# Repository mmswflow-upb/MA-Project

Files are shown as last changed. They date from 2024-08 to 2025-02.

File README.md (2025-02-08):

# Microprocessor Architecture Project 🦀
For more details check the [documentation](DOCUMENTATION.md) and how to [set it up](PROJECT-SETUP.md).

## What is this project about?
We had to create a device using electronic components such as sensors, motors, etc and control them using an MCU of 
our choice. The firmware had to be written in Rust using any framework we wanted, I've decided to use the 
[RP Pico W](https://www.raspberrypi.com/documentation/microcontrollers/pico-series.html#raspberry-pi-pico-w) with 
the [embassy](https://embassy.dev/) framework because it was the same one we had been using during the labs. We also had 
to fork the repository of the [course's website](https://embedded-rust-101.wyliodrin.com/) and add our own project 
presentations, then we had to create pull requests that were tested before merging.

## How did it go?
At first I was unsure of what I wanted to create, but then I tried to go with one idea and develop it incrementally. It was 
tough to work with embassy due to my unfamiliarity with the Rust language, it's a pretty tough language to learn and we had
little time to get used to it.

One of the obstacles was trying to work with modules or libraries, which would help me with 
operating the peripherals connected to my MCU such as the LCD screen or the WIFI chip, 
this is because the community is pretty small and I had to try a couple different modules 
until I found an actual working one.

The toughest part was coming up with the logic for my project, since I had to expect input both 
from a tactile physical remote and an application on the PC simultaneously. This part took
the longest time to finish, because I had to connect my MCU to my laptop each time I tested
the feature.

## What did I learn?
I learned how to work with electronic components, MCUs, I studied communication 
protocols between integrated circuits, I learned some rust along with the embasssy framework, 
I also learned more about app development (with Python), and I learned how to use KiCad and GitHub.

Overall, it was a wonderful learning experience 💪💪

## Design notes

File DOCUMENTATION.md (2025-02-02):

# DIY Laptop Cooling Pad
A cooling Pad for laptops that can be controlled wirelessly or using buttons.

:::info

**Author**: Sakka Mohamad-Mario \
**GitHub Project Link**: https://github.com/mmswflow-upb/MA-Project

:::

## Description

There are 2 possible ways of using it:
* Physically: The fans are controlled through a tactile UI made up of a screen which displays info and buttons with which we increase or decrease the speed of the fans.

* Wirelessly: A user can interact with the microcontroller through a desktop app which sends commands to it through WIFI.

## Motivation

The average temperature around the globe has been on the rise for quite a while, and personally I'm very sensitive to heat, so the first thing that came to my mind was making a fan. After a while I realised that, because I use my laptop for long periods of time doing multiple things including gaming, I also wanted to cool down my laptop's since its keyboard gets pretty hot sometimes when playing games, so I've moved on to this idea. I also wanted the coolers to be controlled using an app on my laptop through wireless connection, without necessarily having to open it, instead I could use key bindings that are preset for the app and I could have the app running in the background.

## Architecture

* The application on the laptop will act as a server, the RP Pico W will establish a connection and it will exchange data with it via TCP to ensure reliable communication between the two. This app will be written in *Python* using the *TTKBootstrap & Socket* modules and it will be converted into an executable. The RP PICO W will connect to a network with preset name & password which must be hosted by the laptop. The
program running on the RP Pico W will be written using the *embassy-rs* framework.

* The physical UI (buttons & LCD) will be used to establish the connection, increase or decrease fan speed, power on or off the setup, with all necessary info being displayed on the LCD.

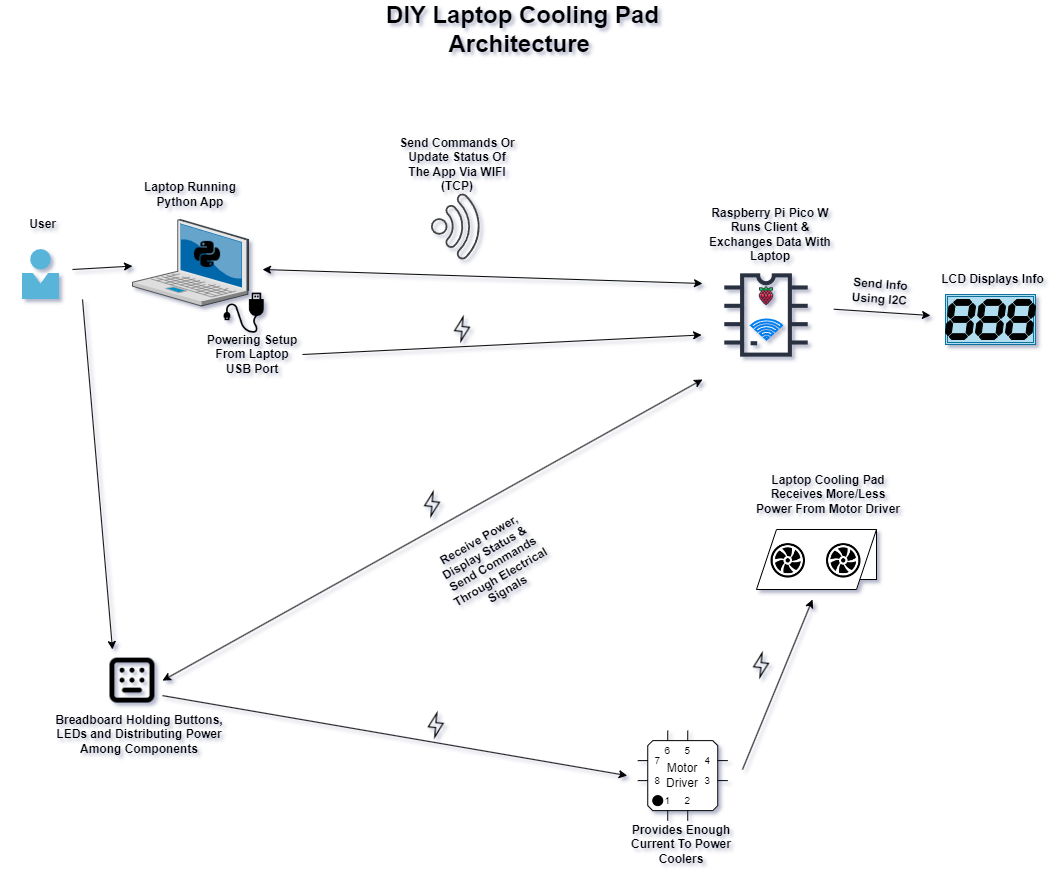
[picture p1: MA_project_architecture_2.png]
architecture
  

## Log

<!-- write every week your progress here -->

### Week 6 - 12 May

I made a laptop pad out of a wood planck, cut 2 holes for the fans and glued the fans into it. I also tested some code that made communication between the RP Pico W & my laptop possible through TCP, and I tested the motor driver. I also tested the firmware for controling the LCD.

### Week 7 - 19 May

I assembled a mini remote with 4 buttons and LEDs that respond to the tactile input or show the status of the circuit, then
I connected the MCU to the motor driver and the fans to the motor driver. I wrote the firmware that handles the tactile input and implemented a debouncer for the push buttons, I also wrote the part of the firmware which displays text on the LCD & controls the motors using PWM. The TCP connection part was partially done and I created the UI for the Python app on the laptop to control the fans through WIFI.

### Week 20 - 26 May
I fixed a bug which did not allow the laptop and MCU to disconnect properly, now the TCP connection can be broken from any of the two sides without any issue, and I've set up the shortcuts for increasing and decreasing the power for the laptop's app, they are set as Left CTRL + I or D for increasing and decreasing the power. I also moved all the buttons and LEDs on the same breadboard which the MCU sits on to save up space. Finally, I have changed the way the currently set power is displayed, I created 3 levels of power (low, medium , high) instead of showing percentages.

## Hardware

* **Raspberry Pi Pico W:** Detecting input and controlling the fans' speed.

* **Breadboard:** Connecting components.

* **Push Buttons** Controlling the speed of the fans.

* **LEDs:** Displaying the status of the cooling pad such as WIFI connection status, powered on or off, increasing or decreasing speed.

* **Rigid Jumper WIres:** Connecting components to breadboard.

* **LCD 1602 I2C:** Displaying info when changing speed, powering on and establishing connection with PC.

* **Cooling Fans:** Used to cool down the laptop.

* **Motor Driver:** Setting the power of the fans through PWM.

### Schematics

* **The KiCAD schematic:**

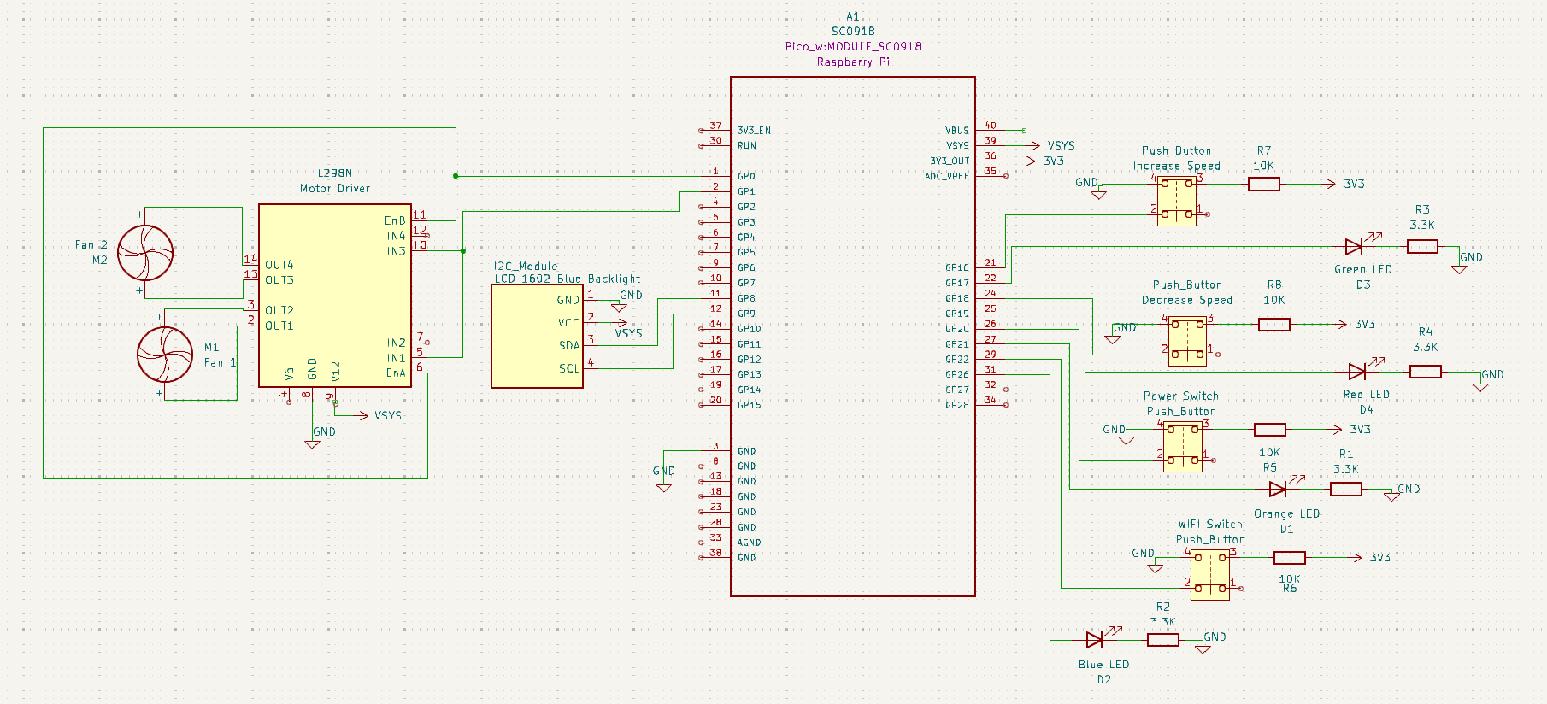
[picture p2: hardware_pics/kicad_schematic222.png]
kicad_schematic


* **In Reality:**
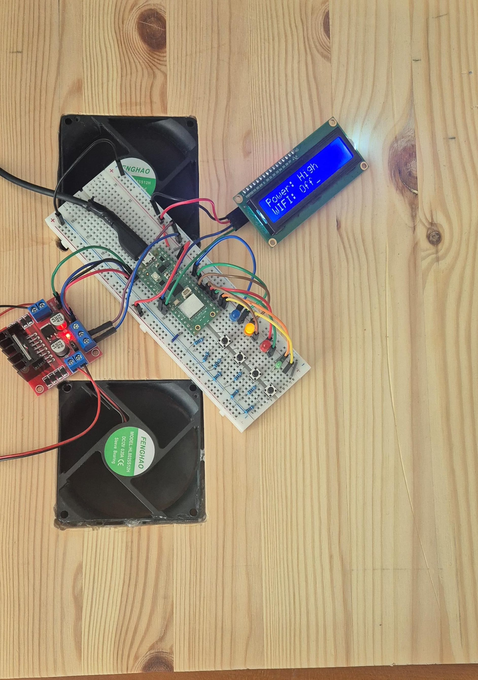
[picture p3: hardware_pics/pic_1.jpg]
hardware pic 1


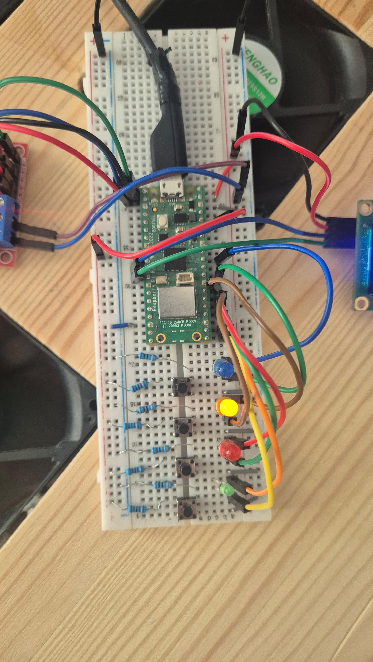
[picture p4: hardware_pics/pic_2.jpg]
hardware pic 2


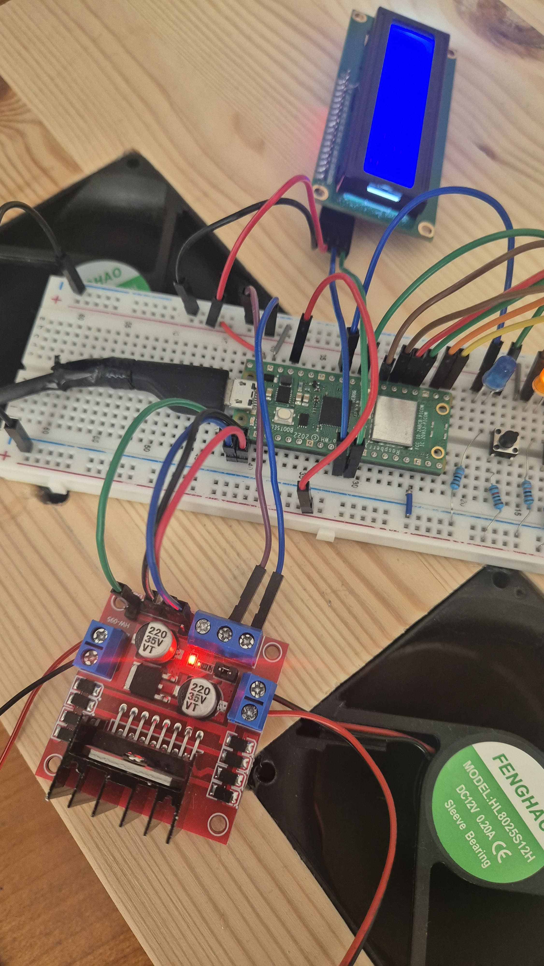
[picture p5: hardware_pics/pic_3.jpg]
hardware_pic 3


### Bill of Materials

<!-- Fill out this table with all the hardware components that you might need.

The format is
```
| [Device](link://to/device) | This is used ... | [price](link://to/store) |

```

-->

| Device | Usage | Price |
|-|-|-|
| [Rapspberry Pi Pico WH](https://www.raspberrypi.com/documentation/microcontrollers/raspberry-pi-pico.html)| The Microcontroller | [1 x 56.23 RON](https://ardushop.ro/ro/home/2819-raspberry-pi-pico-wh.html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) |
| [Data Micro USB Cable](https://static.optimusdigital.ro/31356-large_default/cablu-micro-usb-1-m-alb.jpg) | PC-Microcontroller Communication (Debugging or Flashing Program) | [1 x 3.48 RON](https://www.optimusdigital.ro/ro/cabluri-cabluri-usb/498-cablu-micro-usb-1-m-alb.html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) |
| [Motor Driver](https://ardushop.ro/4686-thickbox_default/l298n-punte-h-dubla-dual-h-bridge-motor-dcsteppe.jpg) | Powering Cooling Fans | [1 x 11.49 RON](https://ardushop.ro/ro/electronica/84-l298n-punte-h-dubla-dual-h-bridge-motor-dcsteppe.html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) |
| [12V 80mm Cooling Fan](https://ardushop.ro/4102-thickbox_default/cooler-carcasa-80-mm.jpg) | Cooling | [2 x 10.84 RON](https://ardushop.ro/ro/home/986-cooler-carcasa-80-mm.html?search_query=ATPNWB_80mm_cooler&results=20)  |
| [1602 LCD with I2C Adaptor](https://static.optimusdigital.ro/55018-large_default/lcd-cu-interfata-i2c-si-backlight-albastru.jpg) | Physical User Interface | [1 x 16.34 RON](https://www.optimusdigital.ro/ro/optoelectronice-lcd-uri/2894-lcd-cu-interfata-i2c-si-backlight-albastru.html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)  | 
| [6x6x6 Push Buttons](https://static.optimusdigital.ro/7679-large_default/buton-6x6x6.jpg) | Physical User Interface | [4 x 0.36 RON](https://www.optimusdigital.ro/ro/butoane-i-comutatoare/1119-buton-6x6x6.html?search_query=buton&results=222) |
| [5mm LEDs](https://ardushop.ro/605-thickbox_default/led-5mm.jpg) | Physical User Interface | [4 x 0.45 RON](https://ardushop.ro/ro/electronica/299-led-5mm.html?search_query=GIISED_LED5_red&results=286#/10-culoare-rou) |
| [830 Points Breadboard](https://static.optimusdigital.ro/54847-large_default/breadboard-830-points.jpg) | Connectivity | [1 x 10.14 RON](https://ardushop.ro/ro/electronica/33-breadboard-830.html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) |
| [Set of Female-Male Wires](https://static.optimusdigital.ro/48492-large_default/set-fire-mama-tata-10p-30-cm.jpg) | Connectivity | [1 x 5.79 RON](https://www.optimusdigital.ro/ro/fire-fire-mufate/879-set-fire-mama-tata-10p-30-cm.html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) |
| [Set of Male-Male Wires](https://static.optimusdigital.ro/48477-large_default/set-fire-tata-tata-10p-10-cm.jpg) | Connectivity | [2 x 2.69 RON](https://www.optimusdigital.ro/ro/fire-fire-mufate/885-set-fire-tata-tata-10p-10-cm.html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) |
| [Set of Rigid Jumper Wires](https://static.optimusdigital.ro/55063-large_default/set-de-fire-pentru-breadboard-rigide.jpg) | Connectivity | [1 x 12.49 RON](https://www.optimusdigital.ro/ro/fire-fire-nemufate/899-set-de-fire-pentru-breadboard-rigide.html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) |
| [Set of Resistors](https://ardushop.ro/7381-thickbox_default/set-rezistente-14w-600buc30-valori-10r-1m.jpg) | Current Modulation | [1 x 12.29 RON](https://ardushop.ro/ro/electronica/212-set-rezistente-14w-600buc30-valori-10r-1m.html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) |
| [DIY Cooling Pad Frame](hardware_pics/coolingpad.jpg) |  Frame That Holds Fans & Laptop | [50 RON] |
| **TOTAL** | - | [**208.55 RON**] |
## Software

| Library | Description | Usage |
|-|-|-|
| [lcd1602-driver](https://github.com/eZioPan/lcd1602-driver) | Display driver for LCD1602 | Used to write strings to LCD display |
| [embassy-time](https://docs.embassy.dev/embassy-executor/git/std/index.html) | Time management library | Delays & debouncing between button pressings |
| [embassy-rp](https://docs.embassy.dev/embassy-rp/git/rp2040/index.html) | Accessing peripherals | Interacting with peripherals (pins) |
| [embassy-executor](https://docs.embassy.dev/embassy-executor/git/std/index.html)| An async/await executor designed for embedded usage | Running multiple tasks simultaneously |
| [log](https://docs.embassy.dev/embassy-usb-logger/git/default/index.html) | Logging interface | Logging info or warning messages |
| [embassy-usb-logger](https://docs.embassy.dev/embassy-usb-logger/git/default/index.html) | USB implementation of the log crate | Logging info or warning messages over USB |
| [embassy-pwm](https://docs.embassy.dev/embassy-nrf/git/nrf52840/pwm/index.html) | PWM driver for embassy | Controlling rotation speed of coolers |
| [embassy-net](https://github.com/embassy-rs/embassy/tree/main/embassy-net) | Networking functionalities for embassy | Creating TCP connections with laptop |
| [embedded-io-async](https://github.com/rust-embedded/embedded-hal/tree/master/embedded-io-async) | Async IO traits for embedded systems | Async writing to buffers |
| [embassy_futures](https://github.com/embassy-rs/embassy/tree/main/embassy-futures) | No-std compatible futures | Event handling such as button presses or data received through wifi | 
| [embassy_sync](https://github.com/embassy-rs/embassy/tree/main/embassy-sync) | Synchronization data structures with async support | Creating MPMC channels for event handling |
| [static_cell](https://github.com/embassy-rs/static-cell) | Statically allocated, initialized at runtime cell | Static variables intialized at runtime|
| [cyw43_pio](https://docs.embassy.dev/cyw43-pio/git/default/index.html) | no-std Rust driver for cyw43 WIFI chip on RP Pico W| Connecting to WIFI network hosted by Laptop |
| [heapless](https://github.com/rust-embedded/heapless) | Heapless data structures | Creating strings that will be displayed on the LCD |
| [TTKBootstrap](https://github.com/israel-dryer/ttkbootstrap) | Python UI-library based on Tkinter & Bootstrap CSS | Building the UI of the desktop app |
| [socket](https://docs.python.org/3/library/socket.html) | Low level networking interface for Python | Handling data exchanges and connections with RP Pico W |
| [keyboard](https://github.com/boppreh/keyboard) | Python library for hooking global keyboard events | Detecting if the shortcuts for increasing or decreasing the power were used |

## Links

<!-- Add a few links that inspired you and that you think you will use for your project -->
* [RP Pico Controlling DC Motor](https://www.tomshardware.com/how-to/dc-motors-raspberry-pi-pico)
* [WebApp Hosted on RP Pico W Used to Control Cooler Through PWM](https://www.youtube.com/watch?v=oDCNkxCHNNQ)
* [embassy-rs wifi server with TCP example](https://github.com/embassy-rs/embassy/blob/main/examples/rp/src/bin/wifi_tcp_server.rs)
* [embassy-rs debouncer struct example](https://github.com/embassy-rs/embassy/blob/main/examples/rp/src/bin/debounce.rs)

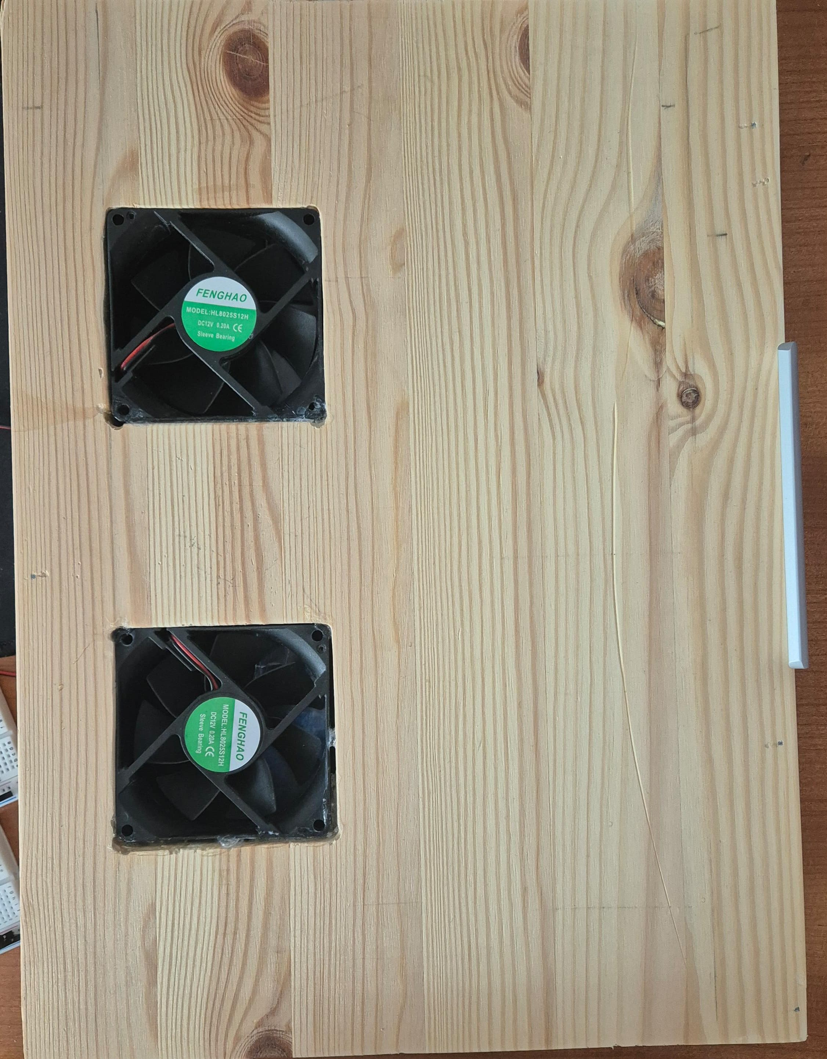
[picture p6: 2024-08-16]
hardware_pics/coolingpad.jpg

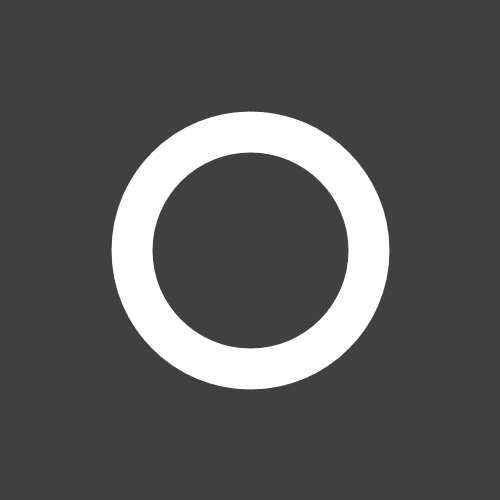
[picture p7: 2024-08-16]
project-files/Python App/assets/light_theme.png

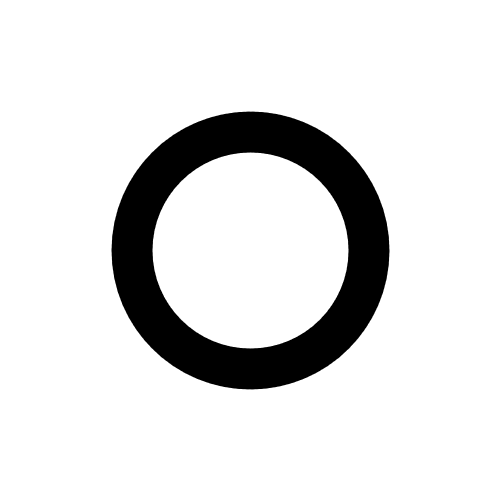
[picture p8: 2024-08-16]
project-files/Python App/assets/dark_theme.png

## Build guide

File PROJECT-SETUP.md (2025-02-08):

# DIY Laptop Cooling Pad - SETUP
Follow these steps for setting up the project (this guide is for windows only)

## RP Pico W Firmware

1. Make sure you have installed the Rust [toolchain manager](https://static.rust-lang.org/rustup/dist/x86_64-pc-windows-msvc/rustup-init.exe),
if everything went well you should get the version of the toolchain in the terminal after running:

```powershell
rustup --version
```

2. Install the dependencies, run this command in the terminal:

```powershell
cargo install 
```

3. Once you have cloned this repo, navigate to the rp_pico_w_firmware folder by running in the terminal

```powershell
cd path/to/MA-project/project-files/rp_pico_w_firmware
```

4. Build the MCU's firmware by running

```powershell
cargo build --release --target thumbv6m-none-eabi
```

5. The KiCAD schematic provides all the necessary information on how to connect the hardware components.

6. Make sure that you have connected your Pico W to your PC via USB

7. Flash the program by running this command

```powershell
elf2uf2-rs -ds .\target\thumbv6m-none-eabi\release\pico_firmware
```

8. Now you can use the cooling pad.

## Python App

1. You must have Python 3.12 installed (or newer)

2. Once you have installed Python, open a terminal and install the following libraries

```powershell
pip install pillow
pip install ttkbootstrap
pip install keyboard
```

3. Navigate to the Python App folder by using the terminal and running

```powershell
cd path/to/MA-project/project-files/"Python App"
```

4. Run the program with the command:

```powershell
python3 coolingstation_client.py
```

5. Now you can use the app to control the cooling pad from the laptop.

## Usage

1. The cooling pad must be turned on by pressing on the push button adjacent to the orange LED

2. Decreasing or increasing the power of the fans is done by pressing the buttons adjacent to the green & red LEDs

3. In order to use the WIFI feature of the cooling pad, you must first turn on mobile hotspot from your PC

```
Network Name: PicoProjectWifi
Network Password: 12345678
Network Band: 2.4 Ghz
```

5. Turning on the WIFI feature is done by pressing once on the button adjacent to the blue LED, forcing the MCU to try to connect to the laptop's hotspot network

6. Wait until the LCD displays `Wifi: Ready`, then open the app on your PC, and click on connect, wait for a few seconds and done! You can now control the power of the fans from the laptop through WIFI.

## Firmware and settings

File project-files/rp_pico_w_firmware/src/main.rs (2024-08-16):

#![no_std]
#![no_main]

use core::str::{from_utf8, FromStr};

use cortex_m::prelude::_embedded_hal_blocking_delay_DelayMs;

use cyw43_pio::PioSpi;
use embassy_executor::Spawner;
use embassy_net::tcp::TcpSocket;
use embassy_net::{Config, Stack, StackResources};
use embassy_rp::bind_interrupts;
use embassy_rp::gpio::{Input, Level, Output, OutputOpenDrain, Pull};
use embassy_rp::peripherals::{DMA_CH0, PIO0};
use embassy_rp::pio::{InterruptHandler, Pio};
use embassy_time::{with_timeout, Delay, Duration, TimeoutError, Timer};
use embedded_io_async::Write;

use embassy_rp::i2c::{Config as I2cConfig, I2c, InterruptHandler as I2CInterruptHandler};
use embassy_rp::peripherals::I2C0;

use embassy_futures::select::Either3::{First as First_3, Second as Second_3, Third as Third_3};
use embassy_futures::select::Either4::{
    First as First_4, Fourth, Second as Second_4, Third as Third_4,
};
use embassy_futures::select::{select3, select4};
use static_cell::StaticCell;

use heapless::String;
use lcd1602_driver::command::{self, State};
use lcd1602_driver::lcd::{self, Basic, Ext};
use lcd1602_driver::sender;
use log::{info, warn};

use embassy_rp::pwm::{Config as PwmConfig, Pwm};
use embassy_sync::blocking_mutex::raw::ThreadModeRawMutex;
use embassy_sync::channel::{Channel as MPMC_Channel, Receiver, Sender};

// USB driver
use embassy_rp::peripherals::USB;
use embassy_rp::usb::{Driver, InterruptHandler as USBInterruptHandler};

use panic_probe as _;

//ENUMS for channels, we use these when we switch the circuit on or off, or when we want the connection task to resume or pause

enum PowerCommand {
    Increase,
    Decrease,
}

// STRUCTS

//Debouncer struct, used to debounce the buttons
pub struct Debouncer<'a> {
    input: Input<'a>,
    debounce: u16,
}

impl<'a> Debouncer<'a> {
    pub fn new(input: Input<'a>, debounce: u16) -> Self {
        Self { input, debounce }
    }

    pub async fn debounce(&mut self) -> Level {
        loop {
            let l1 = self.input.get_level();

            self.input.wait_for_any_edge().await;

            Delay::delay_ms(&mut Delay, self.debounce);

            let l2 = self.input.get_level();
            if l1 != l2 {
                break l2;
            }
        }
    }
}

//CONSTANTS

const TOP: u16 = 0x8000; //This is the top value for the PWM
const DISPLAY_FREQUENCY: u32 = 100_000; //This is the frequency of the display
const LCD_ADDR: u8 = 0x27; //This is the address of the LCD
const WIFI_NETWORK: &str = "PicoProjectWifi";
const WIFI_PASSWORD: &str = "12345678";
const DEBOUNCE: u16 = 100; //This is the debounce time for the buttons [in ms]
const BUTTONS_TASK_DELAY: u64 = 400; //This is the delay for the buttons tasks [in ms]
const SPEED_CHANGE_DELAY: Duration = Duration::from_millis(400); //This is the delay for the power change [in ms]

/*CHANNELS:
- SPEED_CONTROL_CHANNEL: MPMC Channel for sending power commands to the main task
- SEND_OVER_CONNECTION_CHANNEL: MPMC Channel for sending data to the exchange over connection task
- SETUP_SWITCH_CHANNEL: MPMC Channel for sending signals to main to stop  the laptop pad from doing anything until power is switched on again
    - WIFI_SWITCH_CHANNEL: MPMC Channel for sending signals to the main task to switch wifi on or off
    - WIFI_MAIN_SWITCH_CHANNEL: MPMC Channel for sending signals to the exchange over connection task to switch wifi on or off
    - WIFI_CONNECTION_BREAK_CHANNEL: MPMC Channel for sending signals to the main task to notify it that the connection has been broken
    - CONNECTION_READY_CHANNEL: MPMC Channel for sending signals to the exchange over connection task to notify it that the connection is ready to be used

*/
static SPEED_CONTROL_CHANNEL: MPMC_Channel<ThreadModeRawMutex, (PowerCommand, bool), 64> =
    MPMC_Channel::new();
static SEND_OVER_CONNECTION_CHANNEL: MPMC_Channel<ThreadModeRawMutex, u8, 64> = MPMC_Channel::new();
static SETUP_SWITCH_CHANNEL: MPMC_Channel<ThreadModeRawMutex, bool, 64> = MPMC_Channel::new();
static WIFI_BTN_SWITCH_CHANNEL: MPMC_Channel<ThreadModeRawMutex, bool, 64> = MPMC_Channel::new();
static WIFI_MAIN_SWITCH_CHANNEL: MPMC_Channel<ThreadModeRawMutex, bool, 64> = MPMC_Channel::new();
static WIFI_CONNECTION_BREAK_CHANNEL: MPMC_Channel<ThreadModeRawMutex, bool, 64> =
    MPMC_Channel::new();
static CONNECTION_READY_CHANNEL: MPMC_Channel<ThreadModeRawMutex, bool, 64> = MPMC_Channel::new();
bind_interrupts!(struct Irqs {
    USBCTRL_IRQ => USBInterruptHandler<USB>;
    // PIO interrupt for CYW SPI communication
    PIO0_IRQ_0 => InterruptHandler<PIO0>;
    I2C0_IRQ => I2CInterruptHandler<I2C0>;
});

//useful functions
fn match_power(power: u8) -> String<32> {
    match power {
        80 => {
            return String::<32>::try_from("Power: Medium").unwrap();
        }
        100 => {
            return String::<32>::try_from("Power: High").unwrap();
        }
        _ => {
            return String::<32>::try_from("Power: Low").unwrap();
        }
    }
}

//UTILITY TASKS

#[embassy_executor::task]
async fn logger_task(driver: Driver<'static, USB>) {
    embassy_usb_logger::run!(1024, log::LevelFilter::Info, driver);
}

#[embassy_executor::task]
async fn wifi_task(
    runner: cyw43::Runner<'static, Output<'static>, PioSpi<'static, PIO0, 0, DMA_CH0>>,
) -> ! {
    runner.run().await
}

#[embassy_executor::task]
async fn net_task(stack: &'static Stack<cyw43::NetDriver<'static>>) -> ! {
    stack.run().await
}

#[embassy_executor::task]
async fn exchange_over_connection(
    mut wifi_control: cyw43::Control<'static>,
    stack: &'static Stack<cyw43::NetDriver<'static>>,
    power_control_sender: Sender<'static, ThreadModeRawMutex, (PowerCommand, bool), 64>,
    send_over_connection_receiver: Receiver<'static, ThreadModeRawMutex, u8, 64>,
    main_to_connection_receiver: Receiver<'static, ThreadModeRawMutex, bool, 64>,
    mut blue_led: Output<'static>,
) {
    //This tells the task if it's supposed to try to connect to the network
    let mut active: bool = false;
    let mut connected_to_wifi = false;
    let wifi_connection_timeout = Duration::from_secs(100);
    let mut fan_power: u8 = 0;
    //Buffers for receiving and sending data
    let mut rx_buffer = [0; 4096];
    let mut tx_buffer = [0; 4096];
    let mut buffer: [u8; 1] = [0; 1];
    let mut receive_buffer: [u8; 4096] = [0; 4096];

    //Wait for the connection switch signal to be received
    loop {
        Timer::after_millis(100).await;
        //If active is true, try to connect to the network
        if active {
            //Join Laptop's Hotspot on 2.4Ghz
            if !connected_to_wifi {
                info!("Joining network");

                loop {
                    match with_timeout(
                        wifi_connection_timeout,
                        wifi_control.join_wpa2(WIFI_NETWORK, WIFI_PASSWORD),
                    )
                    .await
                    {
                        Ok(Ok(_)) => {
                            while !stack.is_config_up() {
                                Timer::after_millis(100).await;
                            }
                            info!("DHCP Configured");
                            CONNECTION_READY_CHANNEL.send(true).await;
                            connected_to_wifi = true;
                            break;
                        }
                        Ok(Err(err)) => {
                            info!("Could not join network: {}", err.status);
                            active = false;
                            blue_led.set_low();
                            CONNECTION_READY_CHANNEL.send(false).await;
                            break;
                        }
                        Err(TimeoutError) => {
                            info!("Connection timeout");
                            active = false;
                            blue_led.set_low();
                            CONNECTION_READY_CHANNEL.send(false).await;
                            break;
                        }
                    }
                }
            }

            //Failing to join network will break the process of trying to connect to the network
            if !active {
                continue;
            }
            //Establish TCP Connection
            info!("Creating TCP Socket");
            let mut tcp_socket = TcpSocket::new(stack, &mut rx_buffer, &mut tx_buffer);

            //Establish TCP connection on port 1234, if it fails,  continue looping until it's successful
            info!("Establishing TCP Connection");
            loop {
                match with_timeout(wifi_connection_timeout, tcp_socket.accept(1234)).await {
                    Ok(Ok(_)) => {
                        info!("TCP connection established");
                        CONNECTION_READY_CHANNEL.send(true).await;
                        break;
                    }
                    Ok(Err(e)) => {
                        warn!("TCP connection couldn't be established:  {:?}", e);
                        active = false;
                        connected_to_wifi = false;
                        blue_led.set_low();
                        wifi_control.leave().await;
                        CONNECTION_READY_CHANNEL.send(false).await;
                        break;
                    }
                    Err(TimeoutError) => {
                        info!("TCP connection timeout");
                        active = false;
                        connected_to_wifi = false;
                        blue_led.set_low();
                        wifi_control.leave().await;
                        CONNECTION_READY_CHANNEL.send(false).await;
                        break;
                    }
                }
            }

            //Listen for signals from the channels
            info!("Listening for signals");

            while active {
                Timer::after_millis(100).await;

                match tcp_socket.may_recv() {
                    true => {}
                    false => {
                        info!("Connection lost");
                        active = false;
                        connected_to_wifi = false;
                        tcp_socket.abort();
                        wifi_control.leave().await;
                        blue_led.set_low();
                        WIFI_CONNECTION_BREAK_CHANNEL.send(true).await;
                    }
                }

                let sig = select3(
                    main_to_connection_receiver.receive(),
                    send_over_connection_receiver.receive(),
                    tcp_socket.read(&mut receive_buffer),
                )
                .await;
                info!("Received signal");
                //Match the signal received from the 3 channels
                match sig {
                    //If the connection switch signal is false, set active to false and turn off the blue led
                    First_3(mode) => match mode {
                        false => {
                            info!(
                                "Switching off connection, we're sending the laptop the 111 code"
                            );
                            buffer[0] = 111;

                            match tcp_socket.write_all(&buffer).await {
                                Ok(_) => {
                                    info!("Sent the 111 code to the laptop");
                                }
                                Err(e) => {
                                    warn!("Couldn't send the 111 code to the laptop: {:?}", e);
                                }
                            };
                            match tcp_socket.flush().await {
                                Ok(_) => {
                                    info!("The laptop probably received the 111 code");
                                    tcp_socket.abort();
                                    match wifi_control.leave().await {
                                        _ => {
                                            info!("Left the network");
                                        }
                                    }
                                }
                                Err(e) => {
                                    warn!("Laptop Couldn't receive the 111 code: {:?}", e);
                                }
                            }
                            connected_to_wifi = false;
                            active = false;
                            blue_led.set_low();
                        }
                        _ => {}
                    },

                    //Receive command to send the power over the connection
                    Second_3(received_power) => {
                        if active {
                            info!("Sending Power");
                            fan_power = received_power;
                            buffer[0] = received_power;
                            info!("Buffer: {:?}", buffer);
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
async fn main(spawner: Spawner) {
    //INITIALIZING VARIABLES
    let mut on: bool = false; //This is the state of the circuit, if it's on or off
    let mut wifi_on: bool = false; //This is the state of the wifi, if it's on or off
    let mut power: u8 = 0; //This is the power of the fans

    // Init peripherals
    let peripherals = embassy_rp::init(Default::default());

    // Start USB logger driver
    let usb_driver = Driver::new(peripherals.USB, Irqs);
    spawner.spawn(logger_task(usb_driver)).unwrap();

    // Link CYW43 firmware
    let fw = include_bytes!("../cyw43-firmware/43439A0.bin");
    let clm = include_bytes!("../cyw43-firmware/43439A0_clm.bin");

    // Init SPI for communication with CYW43
    let pwr = Output::new(peripherals.PIN_23, Level::Low);
    let cs = Output::new(peripherals.PIN_25, Level::High);
    let mut pio = Pio::new(peripherals.PIO0, Irqs);
    let spi = PioSpi::new(
        &mut pio.common,
        pio.sm0,
        pio.irq0,
        cs,
        peripherals.PIN_24,
        peripherals.PIN_29,
        peripherals.DMA_CH0,
    );

    // Start Wi-Fi task
    static STATE: StaticCell<cyw43::State> = StaticCell::new();
    let state = STATE.init(cyw43::State::new());
    let (net_device, mut control, runner) = cyw43::new(state, pwr, spi, fw).await;
    spawner.spawn(wifi_task(runner)).unwrap();

    // Init the device
    control.init(clm).await;
    control
        .set_power_management(cyw43::PowerManagementMode::PowerSave)
        .await;

    let cfg = Config::ipv4_static(embassy_net::StaticConfigV4 {
        address: embassy_net::Ipv4Cidr::new(embassy_net::Ipv4Address::new(192, 168, 137, 160), 24),
        dns_servers: heapless::Vec::new(),
        gateway: None,
    });

    // Generate random seed
    let seed = 0x0123_4567_89ab_cdef;

    // Init network stack
    static STACK: StaticCell<Stack<cyw43::NetDriver<'static>>> = StaticCell::new();
    static RESOURCES: StaticCell<StackResources<2>> = StaticCell::new();
    let stack = &*STACK.init(Stack::new(
        net_device,
        cfg,
        RESOURCES.init(StackResources::<2>::new()),
        seed,
    ));

    // Start network stack task
    spawner.spawn(net_task(stack)).unwrap();

    //Initializing LEDs
    let mut orange_led = Output::new(peripherals.PIN_21, Level::Low);
    let mut green_led = Output::new(peripherals.PIN_17, Level::Low);
    let mut red_led = Output::new(peripherals.PIN_19, Level::Low);
    let mut blue_led = Output::new(peripherals.PIN_26, Level::Low);

    //Start Button tasks with 1 second debouncer

    spawner
        .spawn(button_power_switch(Debouncer::new(
            Input::new(peripherals.PIN_20, Pull::Up),
            DEBOUNCE,
        )))
        .unwrap();

    spawner
        .spawn(button_increase_power_pressed(
            Debouncer::new(Input::new(peripherals.PIN_16, Pull::Up), DEBOUNCE),
            SPEED_CONTROL_CHANNEL.sender(),
        ))
        .unwrap();

    spawner
        .spawn(button_decrease_power_pressed(
            Debouncer::new(Input::new(peripherals.PIN_18, Pull::Up), DEBOUNCE),
            SPEED_CONTROL_CHANNEL.sender(),
        ))
        .unwrap();

    spawner
        .spawn(button_wifi_connection(
            Debouncer::new(Input::new(peripherals.PIN_22, Pull::Up), DEBOUNCE),
            WIFI_BTN_SWITCH_CHANNEL.sender(),
        ))
        .unwrap();

    //Start the exchange over connection task
    spawner
        .spawn(exchange_over_connection(
            control,
            stack,
            SPEED_CONTROL_CHANNEL.sender(),
            SEND_OVER_CONNECTION_CHANNEL.receiver(),
            WIFI_MAIN_SWITCH_CHANNEL.receiver(),
            blue_led,
        ))
        .unwrap();

    // INIT LCD

    let mut displayed_sentence = String::<32>::from_str("State: OFF").unwrap();

    let sda = peripherals.PIN_8;
    let scl = peripherals.PIN_9;

    let mut i2c = I2c::new_async(peripherals.I2C0, scl, sda, Irqs, I2cConfig::default());
    let mut sender = sender::I2cSender::new(&mut i2c, LCD_ADDR);
    let lcd_config = lcd::Config::default();
    let mut delayer = Delay;
    let mut lcd = lcd::Lcd::new(&mut sender, &mut delayer, lcd_config, DISPLAY_FREQUENCY);
    lcd.set_cursor_blink_state(State::Off);

    lcd.set_cursor_pos((0, 0));
    lcd.write_str_to_cur(&displayed_sentence);

    //INIT PWM

    let _direction_motors = Output::new(peripherals.PIN_1, Level::High);

    let mut config_pwm_motors: PwmConfig = Default::default();
    config_pwm_motors.top = TOP;
    config_pwm_motors.compare_a = 0x0000;

    let mut pwm_motors = Pwm::new_output_a(
        peripherals.PWM_SLICE0,
        peripherals.PIN_0,
        config_pwm_motors.clone(),
    );

    //Start main loop and listen for signals from channels & handle them
    loop {
        lcd.set_cursor_blink_state(State::Off);

        Timer::after_millis(100).await;

        let sig = select4(
            WIFI_CONNECTION_BREAK_CHANNEL.receive(),
            WIFI_BTN_SWITCH_CHANNEL.receive(),
            SETUP_SWITCH_CHANNEL.receive(),
            SPEED_CONTROL_CHANNEL.receive(),
        )
        .await;

        match sig {
            First_4(_) => {
                //If the connection is broken, turn off the blue led & set wifi to off
                wifi_on = false;

                displayed_sentence = String::<32>::try_from("WIFI: Off").unwrap();
                lcd.set_cursor_pos((0, 1));
                lcd.write_str_to_cur(&displayed_sentence);
            }

            Second_4(_) => {
                if on == true {
                    lcd.clean_display();
                    displayed_sentence = String::<32>::try_from("Connecting...").unwrap();
                    lcd.set_cursor_pos((0, 0));
                    lcd.write_str_to_cur(&displayed_sentence);

                    //If the wifi button is pressed, switch wifi on or off
                    wifi_on = !wifi_on;
                    WIFI_MAIN_SWITCH_CHANNEL.send(wifi_on).await;

                    if wifi_on {
                        //First for connecting to wifi network
                        match CONNECTION_READY_CHANNEL.receive().await {
                            true => {
                                lcd.clean_display();
                                displayed_sentence = String::<32>::try_from("WIFI: Ready").unwrap();
                                lcd.set_cursor_pos((0, 0));
                                lcd.write_str_to_cur(&displayed_sentence);
                            }
                            false => {
                                wifi_on = false;
                                WIFI_MAIN_SWITCH_CHANNEL.send(false).await;

                                lcd.clean_display();

                                displayed_sentence = match_power(power.clone());

                                lcd.set_cursor_pos((0, 0));
                                lcd.write_str_to_cur(&displayed_sentence);

                                displayed_sentence = String::<32>::try_from("WIFI: Off").unwrap();
                                lcd.set_cursor_pos((0, 1));
                                lcd.write_str_to_cur(&displayed_sentence);
                                continue;
                            }
                        }

                        //Second for TCP connection
                        match CONNECTION_READY_CHANNEL.receive().await {
                            true => {
                                lcd.clean_display();

                                displayed_sentence = match_power(power.clone());

                                lcd.set_cursor_pos((0, 0));
                                lcd.write_str_to_cur(&displayed_sentence);

                                displayed_sentence = String::<32>::try_from("WIFI: On").unwrap();
                                lcd.set_cursor_pos((0, 1));
                                lcd.write_str_to_cur(&displayed_sentence);
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
